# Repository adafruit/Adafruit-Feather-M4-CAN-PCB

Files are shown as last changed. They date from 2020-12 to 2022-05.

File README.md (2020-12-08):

## Adafruit Feather M4 CAN Express PCB

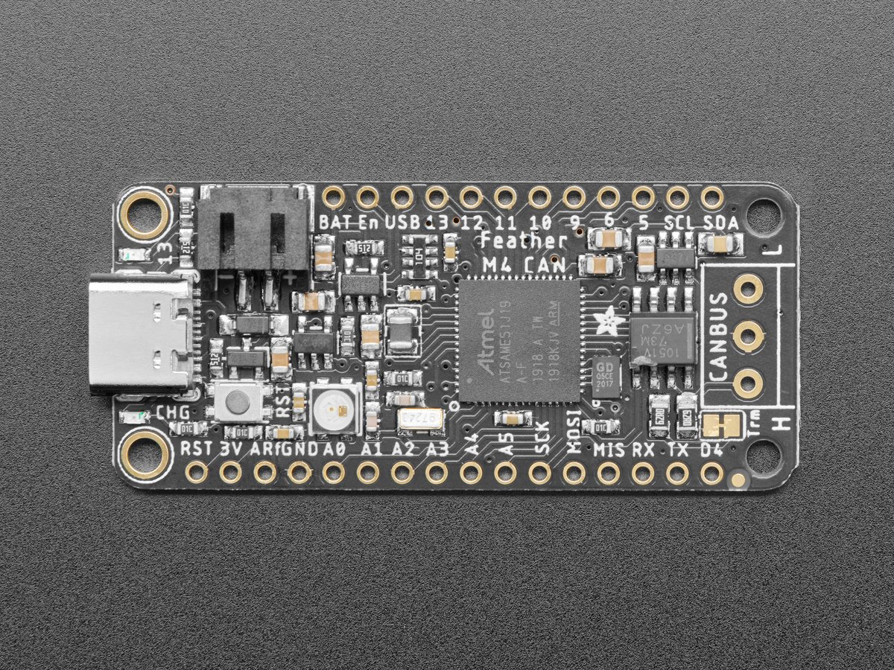
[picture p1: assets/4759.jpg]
<a href="http://www.adafruit.com/products/4759"><br/>
Click here to purchase one from the Adafruit shop</a>

PCB files for the Adafruit Feather M4 CAN Express.

Format is EagleCAD schematic and board layout
* https://www.adafruit.com/product/4759

### Description

One of our favorite Feathers, the Feather M4 Express, gets a glow-up here with an upgrade to the SAME51 chipset which has built-in CAN bus support!  Like its SAMD51 cousin, the ATSAME51J19 comes with a 120MHz Cortex M4 with floating point support and 512KB Flash and 192KB RAM. Your code will zig and zag and zoom, and with a bunch of extra peripherals for support, this will for sure be your favorite new chipset for CAN interfacing projects.

At the end of the board we have placed a CAN transceiver chip as well as a 5V converter to generate 5V power to the transceiver even when running on battery. The two CAN signal lines and ground reference signal are available on a 3-pin 3.5mm terminal block. The chip and booster can be put to sleep for power saving. The built in CAN can read or write packets and has support in both Arduino and CircuitPython.

And best of all, it's a Feather - so you know it will work with all our FeatherWings! What a great way to quickly get up and running. It's even pin-compatible with the original Feather M4.

The most exciting part of the Feather M4 CAN is that while you can use it with the Arduino IDE - and it's bonkers fast when you do, you can use it with CircuitPython as well. When you plug it in, it will show up as a very small disk drive with main.py on it. Edit main.py with your favorite text editor to build your project using Python, the most popular programming language. No installs, IDE or compiler needed, so you can use it on any computer, even ChromeBooks or computers you can't install software on. When you're done, unplug the Feather and your code will go with you.

Here are some of the updates you can look forward to when using Feather M4 CAN:

* Measures 2.0" x 0.9" x 0.28" (50.8mm x 22.8mm x 7mm) without headers soldered in
* Light as a (large?) feather - 5 grams
* ATSAME51 32-bit Cortex M4 core running at 120 MHz, 32-bit, 3.3V logic and power
* Hardware CAN bus support with built-in transceiver, 5V booster and terminal connection.
* Floating point support with Cortex M4 DSP instructions
* 512 KB flash, 192 KB RAM
* 2 MB SPI FLASH chip for storing files and CircuitPython code storage.
* No EEPROM
* 32.768 KHz crystal for clock generation & RTC
* 3.3V regulator with 500mA peak current output
* USB Type C connector for USB native support, comes with USB bootloader and serial port debugging
* Built in crypto engines with AES (256 bit), true RNG, Pubkey controller
* Tons of GPIO! 21 x GPIO pins with following capabilities:
  * Dual 1 MSPS 12 bit true analog DAC (A0 and A1) - can be used to play 12-bit stereo audio clips
  * Dual 1 MSPS 12 bit ADC (6 analog pins some on ADC1 and some on ADC2)
  * 6 x hardware SERCOM - Native hardware SPI, I2C and Serial all available
  * 16 x PWM outputs - for servos, LEDs, etc
  * I2S input and output
  * 8-bit Parallel capture controller (for camera/video in)
* Built in 100mA lipoly charger with charging status indicator LED
* Pin #13 red LED for general purpose blinking
* Power/enable pin
* 4 mounting holes
* Reset button

The Feather M4 Can Express also comes with a Mini NeoPixel and 2 MB SPI Flash storage. You can use the SPI Flash storage like a very tiny hard drive. When used in CircuitPython, the 2 MB flash acts as storage for all your scripts, libraries and files. When used in Arduino, you can read/write files to it, like a little datalogger or SD card, and then with our helper program, access the files over USB.

Easy reprogramming: the Feather M4 CAN comes pre-loaded with the UF2 bootloader, which looks like a USB storage key. Simply drag firmware on to program, no special tools or drivers needed! It can be used to load up CircuitPython or Arduino IDE (it is bossa-compatible)

Comes fully assembled and tested, with the UF2 USB bootloader. We also toss in some headers so you can solder it in and plug into a solderless breadboard.

Lipoly battery and USB cable not included (but we do have lots of options in the shop if you'd like!)

### License

Adafruit invests time and resources providing this open source design, please support Adafruit and open-source hardware by purchasing products from [Adafruit](https://www.adafruit.com)!

Designed by Limor Fried/Ladyada for Adafruit Industries.

Creative Commons Attribution/Share-Alike, all text above must be included in any redistribution.
See license.txt for additional details.

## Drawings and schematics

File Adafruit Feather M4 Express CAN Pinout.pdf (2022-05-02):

# Adafruit Feather M4 Express CAN

# https://www.adafruit.com/product/4759

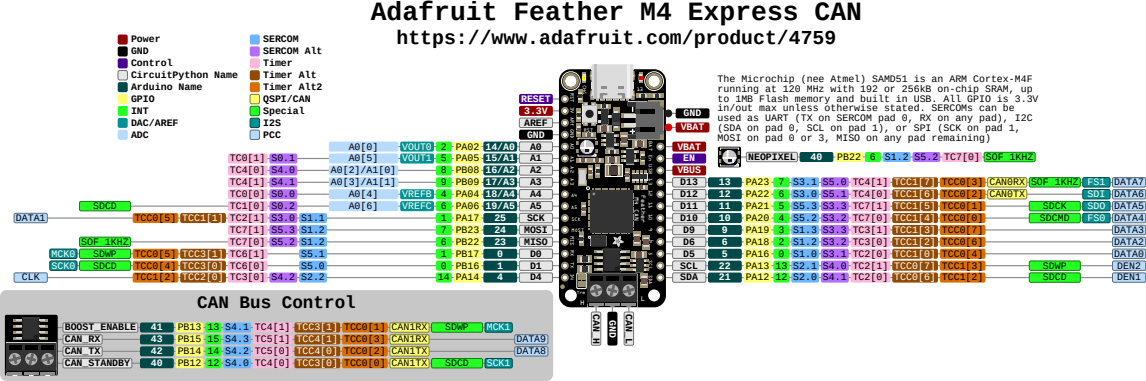
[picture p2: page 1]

The Microchip (nee Atmel) SAMD51 is an ARM Cortex-M4F
running at 120 MHz with 192 or 256kB on-chip SRAM, up
to 1MB Flash memory and built in USB. All GPIO is 3.3V
in/out max unless otherwise stated. SERCOMs can be
used as UART (TX on SERCOM pad 0, RX on any pad), I2C
(SDA on pad 0, SCL on pad 1), or SPI (SCK on pad 1,
MOSI on pad 0 or 3, MISO on any pad remaining)

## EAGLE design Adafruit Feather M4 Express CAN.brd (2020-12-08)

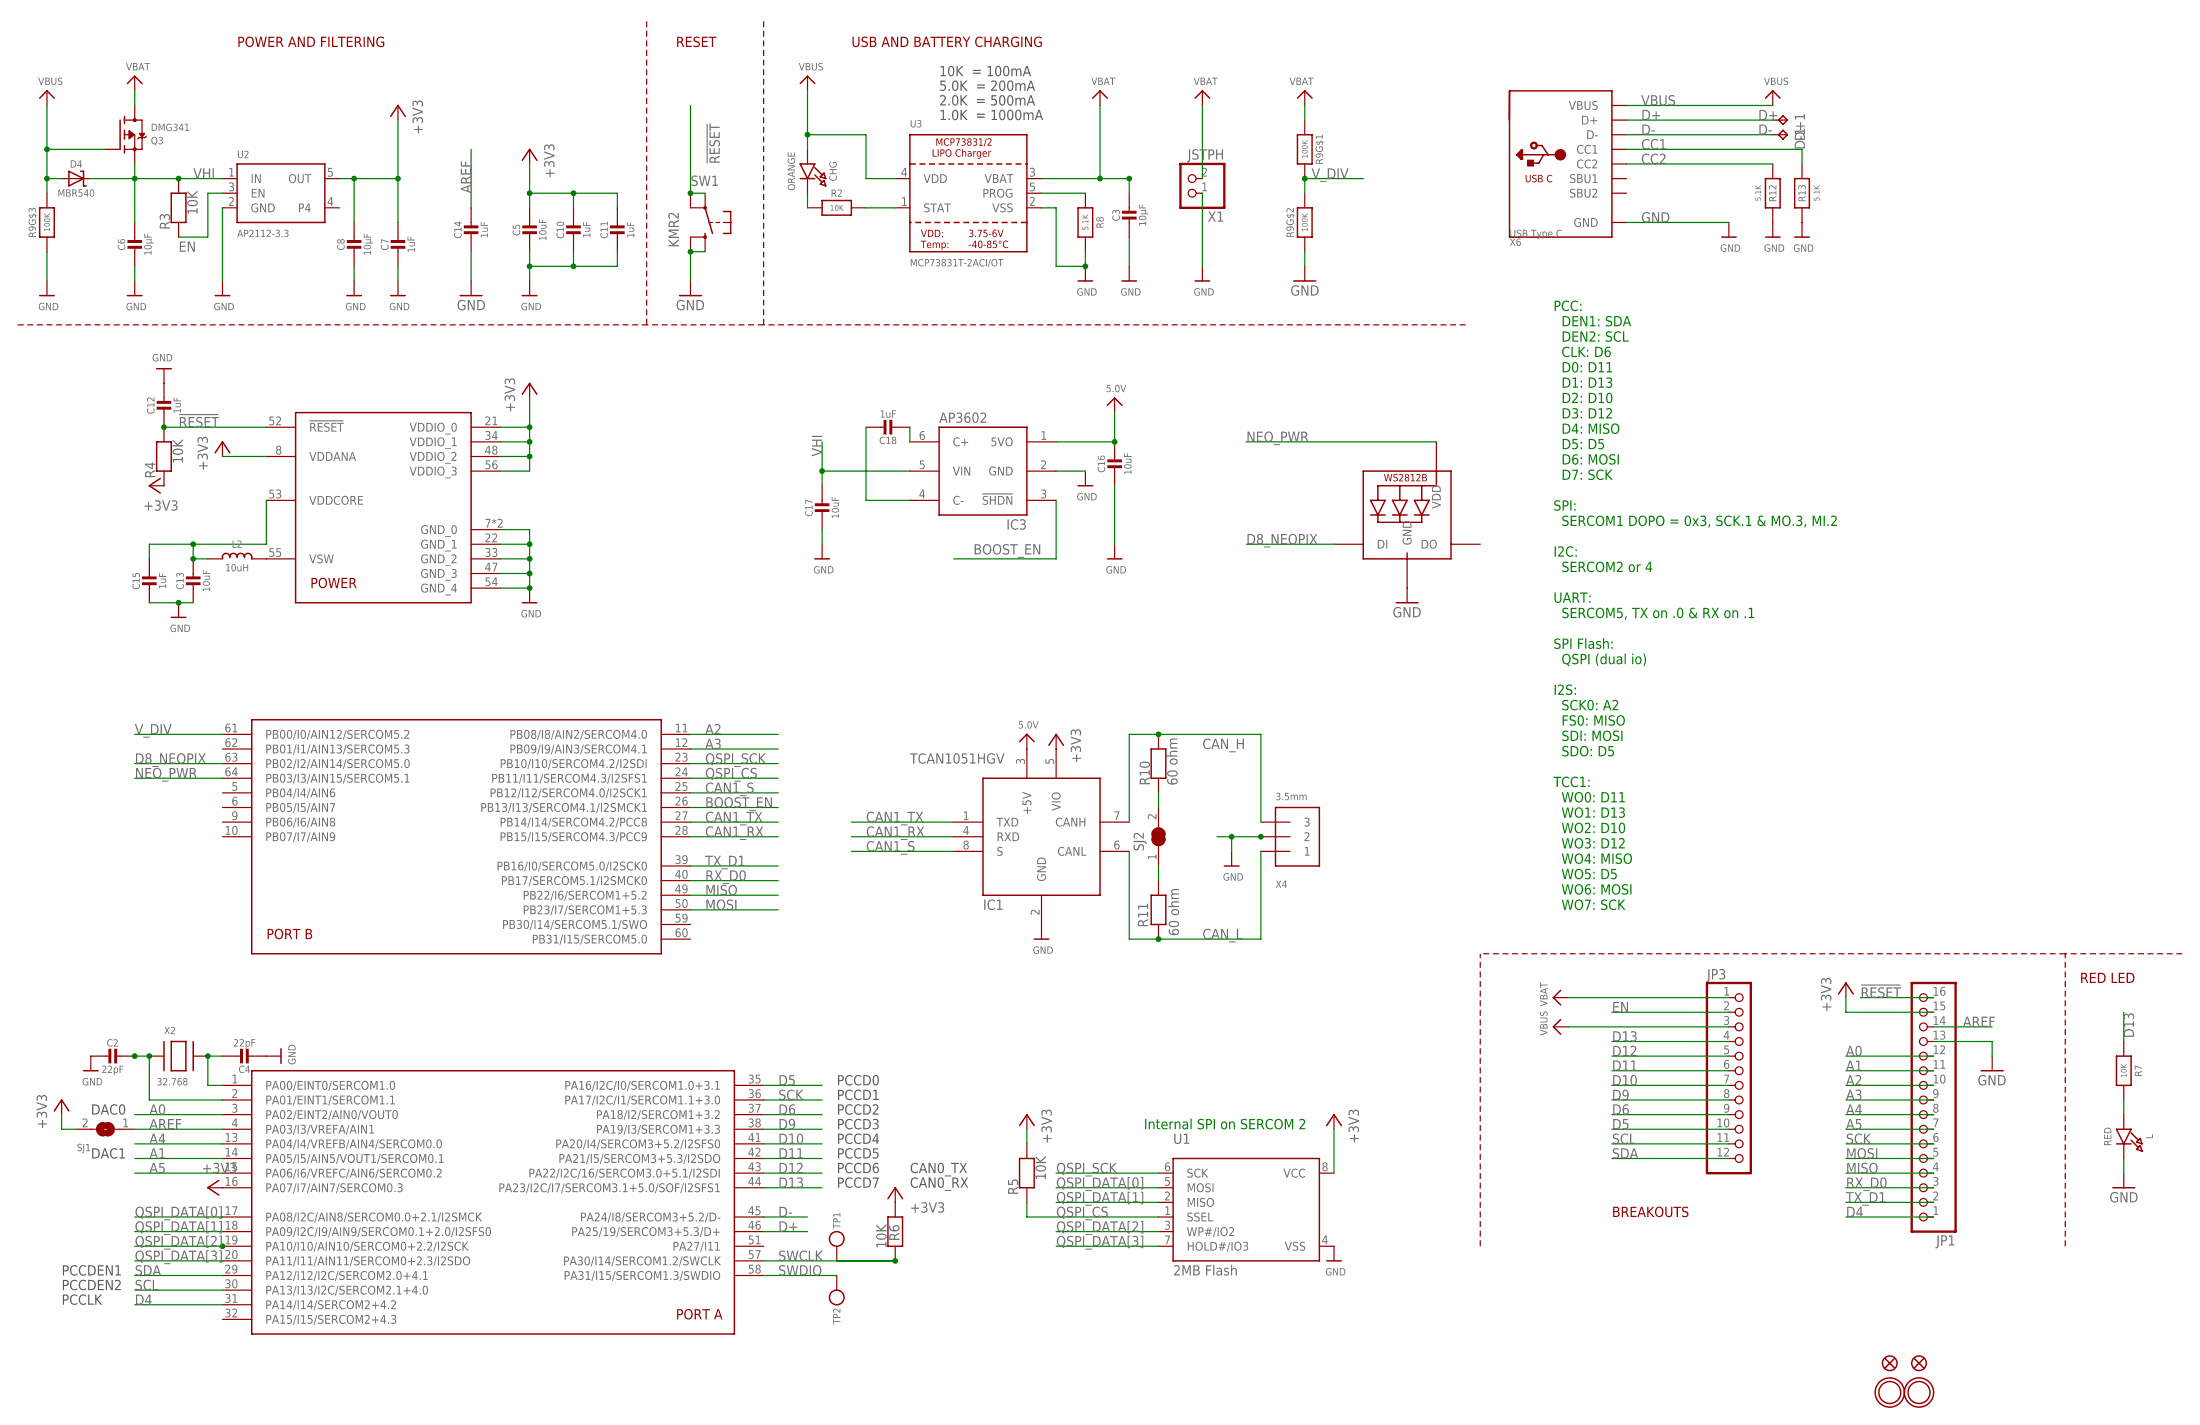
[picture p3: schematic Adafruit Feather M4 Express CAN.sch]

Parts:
C2, C4: 22pF; 0603-NO
C3, C6, C8: 10µF; 0805-NO
C5, C13, C17: 10uF; 0805-NO
C7, C10, C11, C12, C14, C15: 1uF; 0603-NO
C16: 10uF; _0805MP
C18: 1uF; 0805_10MGAP
CHG: ORANGE; CHIPLED_0603_NOOUTLINE
D4: MBR540; SOD-123
D+1: TPB1,27; B1,27
D-1: TPB1,27; B1,27
IC1: TCAN1051HGV; SOIC8_150MIL
IC3: AP3602; SOT23-6
JP1: HEADER-1X16ROUND; 1X16_ROUND
JP3: HEADER-1X12; 1X12_ROUND
L: RED; CHIPLED_0603_NOOUTLINE
L2: 10uH; INDUCTOR_1007
LED1: WS2812B3535; LED3535
Q3: DMG341; SOT23-R
R2, R3, R4, R5, R6, R7: 10K; 0603-NO
R8, R12, R13: 5.1K; 0603-NO
R9: 100K; RESPACK_4X0603_NO
R10, R11: 60 ohm; 0805-NO
SJ1: SOLDERJUMPERCLOSED; SOLDERJUMPER_CLOSEDWIRE
SJ2: SOLDERJUMPER_CLOSED; SOLDERJUMPER_CLOSEDWIRE
SW1: KMR2; BTN_KMR2_4.6X2.8
TP1, TP2: TESTPOINTROUND1.5MM; TESTPOINT_ROUND_1.5MM
U1: 2MB Flash; USON8
U2: AP2112-3.3; SOT23-5@1
U3: MCP73831T-2ACI/OT; SOT23-5
U$14: ATSAMD51J; PQFN64-1
U$31, U$32: MOUNTINGHOLE2.5; MOUNTINGHOLE_2.5_PLATED
U$34, U$35: FIDUCIAL_1MM
X1: JSTPH; JSTPH2_BATT
X2: 32.768; XTAL3215
X4: 3.5mm; TERMBLOCK_1X3-3.5MM
X6: USB Type C; USB_C_CUSB31-CFM2AX-01-X

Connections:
5.0V: C16.1, IC1.3 (+5V), IC3.1 (5VO)
!RESET: C12.2, JP1.16, R4.2, SW1.A, SW1.A' (P1), U$14.52 (!RESET)
+3V3: C5.1, C7.1, C8.1, C10.1, C11.1, IC1.5 (VIO), JP1.15, R4.1, R5.2, R6.1, SJ1.2, U1.8 (VCC), U2.5 (OUT), U$14.8 (VDDANA), U$14.16 (PA07/I7/AIN7/SERCOM0.3), U$14.21 (VDDIO_0), U$14.34 (VDDIO_1), U$14.48 (VDDIO_2), U$14.56 (VDDIO_3)
A0: JP1.12, U$14.3 (PA02/EINT2/AIN0/VOUT0)
A1: JP1.11, U$14.14 (PA05/I5/AIN5/VOUT1/SERCOM0.1)
A2: JP1.10, U$14.11 (PB08/I8/AIN2/SERCOM4.0)
A3: JP1.9, U$14.12 (PB09/I9/AIN3/SERCOM4.1)
A4: JP1.8, U$14.13 (PA04/I4/VREFB/AIN4/SERCOM0.0)
A5: JP1.7, U$14.15 (PA06/I6/VREFC/AIN6/SERCOM0.2)
AREF: C14.1, JP1.14, SJ1.1, U$14.4 (PA03/I3/VREFA/AIN1)
BOOST_EN: IC3.3 (!SHDN), U$14.26 (PB13/I13/SERCOM4.1/I2SMCK1)
CAN1_RX: IC1.4 (RXD), U$14.28 (PB15/I15/SERCOM4.3/PCC9)
CAN1_S: IC1.8 (S), U$14.25 (PB12/I12/SERCOM4.0/I2SCK1)
CAN1_TX: IC1.1 (TXD), U$14.27 (PB14/I14/SERCOM4.2/PCC8)
CAN_H: IC1.7 (CANH), R10.2, X4.3
CAN_L: IC1.6 (CANL), R11.2, X4.1
CC1: R13.2, X6.A5 (CC1)
CC2: R12.2, X6.B5 (CC2)
D4: JP1.1, U$14.31 (PA14/I14/SERCOM2+4.2)
D5: JP3.10, U$14.35 (PA16/I2C/I0/SERCOM1.0+3.1)
D6: JP3.9, U$14.37 (PA18/I2/SERCOM1+3.2)
D8_NEOPIX: LED1.1 (DI), U$14.63 (PB02/I2/AIN14/SERCOM5.0)
D9: JP3.8, U$14.38 (PA19/I3/SERCOM1+3.3)
D10: JP3.7, U$14.41 (PA20/I4/SERCOM3+5.2/I2SFS0)
D11: JP3.6, U$14.42 (PA21/I5/SERCOM3+5.3/I2SDO)
D12: JP3.5, U$14.43 (PA22/I2C/16/SERCOM3.0+5.1/I2SDI)
D13: JP3.4, R7.1, U$14.44 (PA23/I2C/I7/SERCOM3.1+5.0/SOF/I2SFS1)
D+: D+1.TP, U$14.46 (PA25/19/SERCOM3+5.3/D+), X6.A6 (D+), X6.B6 (D+)
D-: D-1.TP, U$14.45 (PA24/I8/SERCOM3+5.2/D-), X6.A7 (D-), X6.B7 (D-)
EN: JP3.2, R3.1, U2.3 (EN)
GND: C2.2, C3.2, C4.2, C5.2, C6.2, C7.2, C8.2, C10.2, C11.2, C12.1, C13.2, C14.2, C15.2, C16.2, C17.2, IC1.2 (GND), IC3.2 (GND), JP1.13, L.C, LED1.4 (GND), R8.2, R9.3 (1), R9.7 (2), R12.1, R13.1, SW1.B (S), SW1.B' (S1), U1.4 (VSS), U2.2 (GND), U3.2 (VSS), U$14.7 (GND_0), U$14.22 (GND_1), U$14.33 (GND_2), U$14.47 (GND_3), U$14.54 (GND_4), U$14.EXP (GND_0), X1.1, X4.2, X6.A1B12 (GND), X6.B1A12 (GND)
MISO: JP1.4, U$14.49 (PB22/I6/SERCOM1+5.2)
MOSI: JP1.5, U$14.50 (PB23/I7/SERCOM1+5.3)
unnamed: CHG.C, R2.1
unnamed: L.A, R7.2
unnamed: R2.2, U3.1 (STAT)
unnamed: R8.1, U3.5 (PROG)
unnamed: R10.1, SJ2.2
unnamed: C4.1, U$14.1 (PA00/EINT0/SERCOM1.0), X2.P$2
unnamed: C18.2, IC3.6 (C+)
unnamed: C18.1, IC3.4 (C-)
unnamed: C2.1, U$14.2 (PA01/EINT1/SERCOM1.1), X2.P$1
unnamed: L2.P$2 (2), U$14.55 (VSW)
unnamed: R11.1, SJ2.1
NEO_PWR: LED1.2 (VDD), U$14.64 (PB03/I3/AIN15/SERCOM5.1)
QSPI_CS: R5.1, U1.1 (SSEL), U$14.24 (PB11/I11/SERCOM4.3/I2SFS1)
QSPI_DATA[0]: U1.5 (MOSI), U$14.17 (PA08/I2C/AIN8/SERCOM0.0+2.1/I2SMCK)
QSPI_DATA[1]: U1.2 (MISO), U$14.18 (PA09/I2C/I9/AIN9/SERCOM0.1+2.0/I2SFS0)
QSPI_DATA[2]: U1.3 (WP#/IO2), U$14.19 (PA10/I10/AIN10/SERCOM0+2.2/I2SCK)
QSPI_DATA[3]: U1.7 (HOLD#/IO3), U$14.20 (PA11/I11/AIN11/SERCOM0+2.3/I2SDO)
QSPI_SCK: U1.6 (SCK), U$14.23 (PB10/I10/SERCOM4.2/I2SDI)
RX_D0: JP1.3, U$14.40 (PB17/SERCOM5.1/I2SMCK0)
SCK: JP1.6, U$14.36 (PA17/I2C/I1/SERCOM1.1+3.0)
SCL: JP3.11, U$14.30 (PA13/I13/I2C/SERCOM2.1+4.0)
SDA: JP3.12, U$14.29 (PA12/I12/I2C/SERCOM2.0+4.1)
SWCLK: R6.2, TP1.P$1, U$14.57 (PA30/I14/SERCOM1.2/SWCLK)
SWDIO: TP2.P$1, U$14.58 (PA31/I15/SERCOM1.3/SWDIO)
TX_D1: JP1.2, U$14.39 (PB16/I0/SERCOM5.0/I2SCK0)
VBAT: C3.1, JP3.1, Q3.3 (D), R9.8 (2), U3.3 (VBAT), X1.2
VBUS: CHG.A, D4.A, JP3.3, Q3.1 (G), R9.6 (2), U3.4 (VDD), X6.A4B9 (VBUS), X6.B4A9 (VBUS)
VDDCORE1: C13.1, C15.1, L2.P$1 (1), U$14.53 (VDDCORE)
VHI: C6.1, C17.1, D4.C, IC3.5 (VIN), Q3.2 (S), R3.2, U2.1 (IN)
V_DIV: R9.1, R9.2 (1), U$14.61 (PB00/I0/AIN12/SERCOM5.2)

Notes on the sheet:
POWER AND FILTERING
RESET
10K = 100mA
5.0K = 200mA
2.0K = 500mA
1.0K = 1000mA
USB AND BATTERY CHARGING
BREAKOUTS
RED LED
Internal SPI on SERCOM 2
PCCDEN1
PCCDEN2
PCCD0
PCCD1
PCCD2
PCCD3
PCCD4
PCCD5
PCCD6
PCCD7
PCCLK
PCC: DEN1: SDA DEN2: SCL CLK: D6 D0: D11 D1: D13 D2: D10 D3: D12 D4: MISO D5: D5 D6: MOSI D7: SCK SPI: SERCOM1 DOPO = 0x3, SCK.1 & MO.3, MI.2 I2C: SERCOM2 or 4 UART: SERCOM5, TX on .0 & RX on .1 SPI Flash: QSPI (dual io) I2S: SCK0: A2 FS0: MISO SDI: MOSI SDO: D5 TCC1: WO0: D11 WO1: D13 WO2: D10 WO3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
CAN0_TX
CAN0_RX
DAC0
DAC1

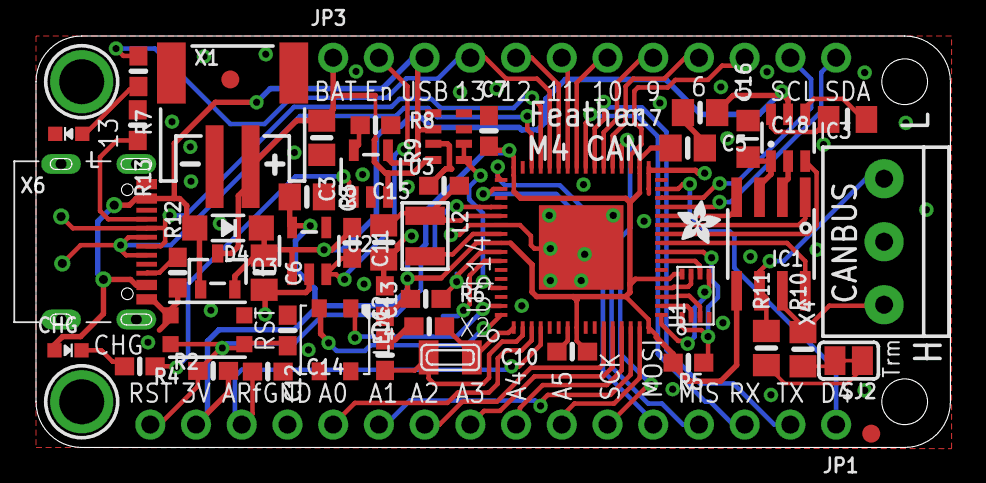
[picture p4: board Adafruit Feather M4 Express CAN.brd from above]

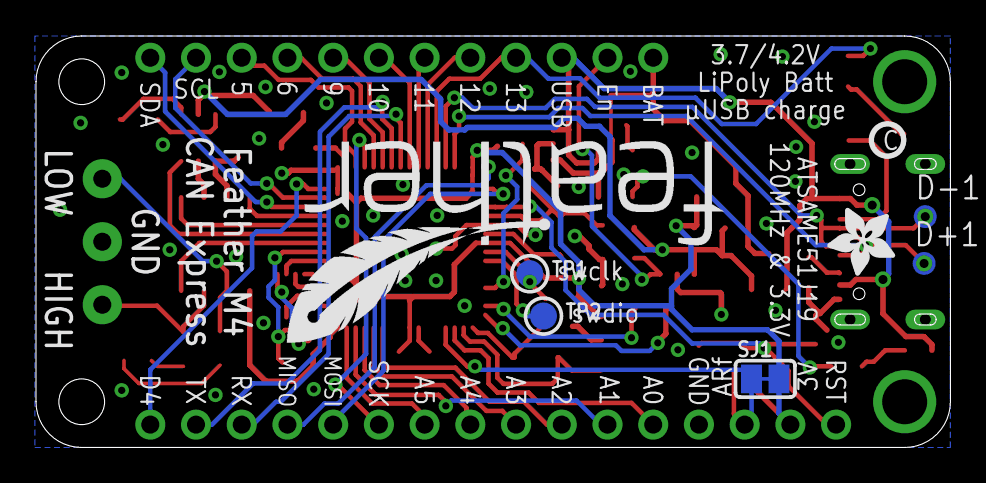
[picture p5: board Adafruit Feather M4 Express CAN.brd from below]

Board: 2 copper layers, 50.8 x 22.9 mm, 61 parts (8 on the bottom side), 63 nets.

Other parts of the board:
U$1: ADAFRUIT_2.5MM
U$9: FEATHERLOGO
U$12: ADAFRUIT_3.5MM
U$13: PCBFEAT-REV-040

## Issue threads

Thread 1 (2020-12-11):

CAN

RudolphRiedel, 2020-12-11:
Hello,

the TCAN1051HGV you are using is "only" rated for 5MBit/s.
You might like to checkout the TCAN1044V which is rated for8MBit/s, comes in SOT23-8 and is a little less expensive.

https://www.ti.com/product/TCAN1044V
https://www.ti.com/product/TCAN1044V-Q1

I designed the hardware for an USB/CAN interface with two isolated CAN channels based on the ATSAME51J19A  a while ago:
https://github.com/RudolphRiedel/USB_CAN-FD

ladyada, 2020-12-12:
thankx will look! the dev board uses the AT6561 which is also only 5 mbs!
https://www.microchip.com/wwwproducts/en/ata6561

ashishsk, 2020-12-18:
Hi,

I have purchased the board and I am curious to check its features. However, I could not find the libraries or examples. Could you link me to them?

Thanks!

RudolphRiedel, 2020-12-18:
I have no use for it as I wrote my own CAN driver for the E51 but after a quick look around I would assume it is this one: https://github.com/adafruit/arduino-CAN

Closed 2020-12-18.

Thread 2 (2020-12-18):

Library support

ashishsk, 2020-12-18:
Hi,

I have purchased the board and I am curious to check its features. However, I could not find the libraries or examples. Could you link me to them?

Thanks!

dherrada, 2020-12-18:
Hey! Here's a guide for the built-in CircuitPython library: https://learn.adafruit.com/using-canio-circuitpython
The docs for the CircuitPython library can be found here: https://circuitpython.readthedocs.io/en/6.0.x/shared-bindings/canio/index.html

If you're looking to use it with Arduino, here's that library: https://github.com/adafruit/arduino-CAN
The Arduino library doesn't say it's compatible with that specific board, but I think it might work

ashishsk, 2020-12-22:
@dherrada Thanks for the links, Dylan. I am trying out the Arduino library and the adafruit fork repo doesn't compile even though it seems like the support for Feather M4 CAN has been added. The error that I am currently encountering is of a missing same51.h.
Any idea if this can be resolved?

dherrada, 2020-12-22:
@ashishsk I'd open an issue on that library. I rarely work with Arduino so I'm not really sure how to help

ladyada, 2021-01-26:
hi thanks for being patient! please check out
https://learn.adafruit.com/adafruit-feather-m4-can-express
for deets. if you need more help please open an issue on the the https://github.com/adafruit/arduino-CAN library, submit a 'feedback' on learning system or post in adafruit forums :)

ashishsk, 2021-01-26:
Thanks for the reply. I have taken your suggestion and did all 3 of them
because that's how important and urgent it is for me to solve this issue. I
bought 10 of these boards on the first release order and I really want to
put it to use since it was a huge investment for me. I hope this issue is
resolved at the earliest.

Regards,
Ashish

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

Closed 2020-12-22.

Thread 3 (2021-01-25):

no learning guide / no examples / no CAN-library / strange neopixel handling in HW & SW

BlackBrix, 2021-01-25:
I bought the Adafruit the Feather M4 CAN in December,
BUT:
When will there be support for the Feather M4 CAN, cause up to now (01-25-2021):
- there's no learning guide so far
- there's no arduino CAN library for the ATSAME51J19 from adafruit (so far) [MCP2515 based only]
- the uf2-bootloader has errors in regards of displaying the correct bootloader status via the neopixel LED
- the arduino package has errors as well in regards of correct Pin-assignment the neopixel PWR Pin
- the neopixel draws way too much current out from the MCU-Output-Pin (MCU-Output-Pin Voltage drops from 3.3V to 2.7V) [an additional FET would be the much better solution as done already on other feather boards]

see as well these forum topics (regarding this 5 issues above):
 - https://forums.adafruit.com/viewtopic.php?f=57&t=174012
 - https://forums.adafruit.com/viewtopic.php?f=57&t=173723

very disappointing customer-experience so far ... :-/

ladyada, 2021-01-25:
yeah its been an 'exciting' few weeks - normally does not take this long! guide is being worked on today :)

ladyada, 2021-01-26:
hi thanks for being patient! please check out
https://learn.adafruit.com/adafruit-feather-m4-can-express
for deets. if you need more help please open an issue on the the https://github.com/adafruit/arduino-CAN library or learning system :)

Closed 2021-01-26.

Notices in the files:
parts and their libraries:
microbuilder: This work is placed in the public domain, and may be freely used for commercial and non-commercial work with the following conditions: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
